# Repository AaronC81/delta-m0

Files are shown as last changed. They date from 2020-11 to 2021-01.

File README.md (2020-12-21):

# Delta M0

## What is this?

Delta M0 is a **basic, compact scientific calculator** based on an STM32F0
microcontroller.

In use | Front | Back
:-:|:-:|:-:
My hand holding the Delta M0, showing the result of 2 plus 2. | The front of the Delta M0. It has a matrix of 4 columns and 5 rows of buttons, a small OLED display, a power switch on the side, and a 6-pin serial programming header on the top. | The back of the Delta M0. It has a JST battery connector on the top, a battery controller IC, an STM32 microcontroller, and some supporting passive components.

## How well does it work?

It does _work_, but you probably don't want to use it as an actual calculator
yet. The software is really lacking.

## Project structure

This is based off the
[libopencm3 template](https://github.com/libopencm3/libopencm3-template).

  - `my-project` contains the C code for the firmware.
  - `test` is a small set of unit tests which you can run with `./test/run`.
  - `hardware` contains the KiCad files for the PCB. 

# Building

Make sure you clone with `--recurse-submodules`!

Then:

```
make -C libopencm3
make -C my-project
```

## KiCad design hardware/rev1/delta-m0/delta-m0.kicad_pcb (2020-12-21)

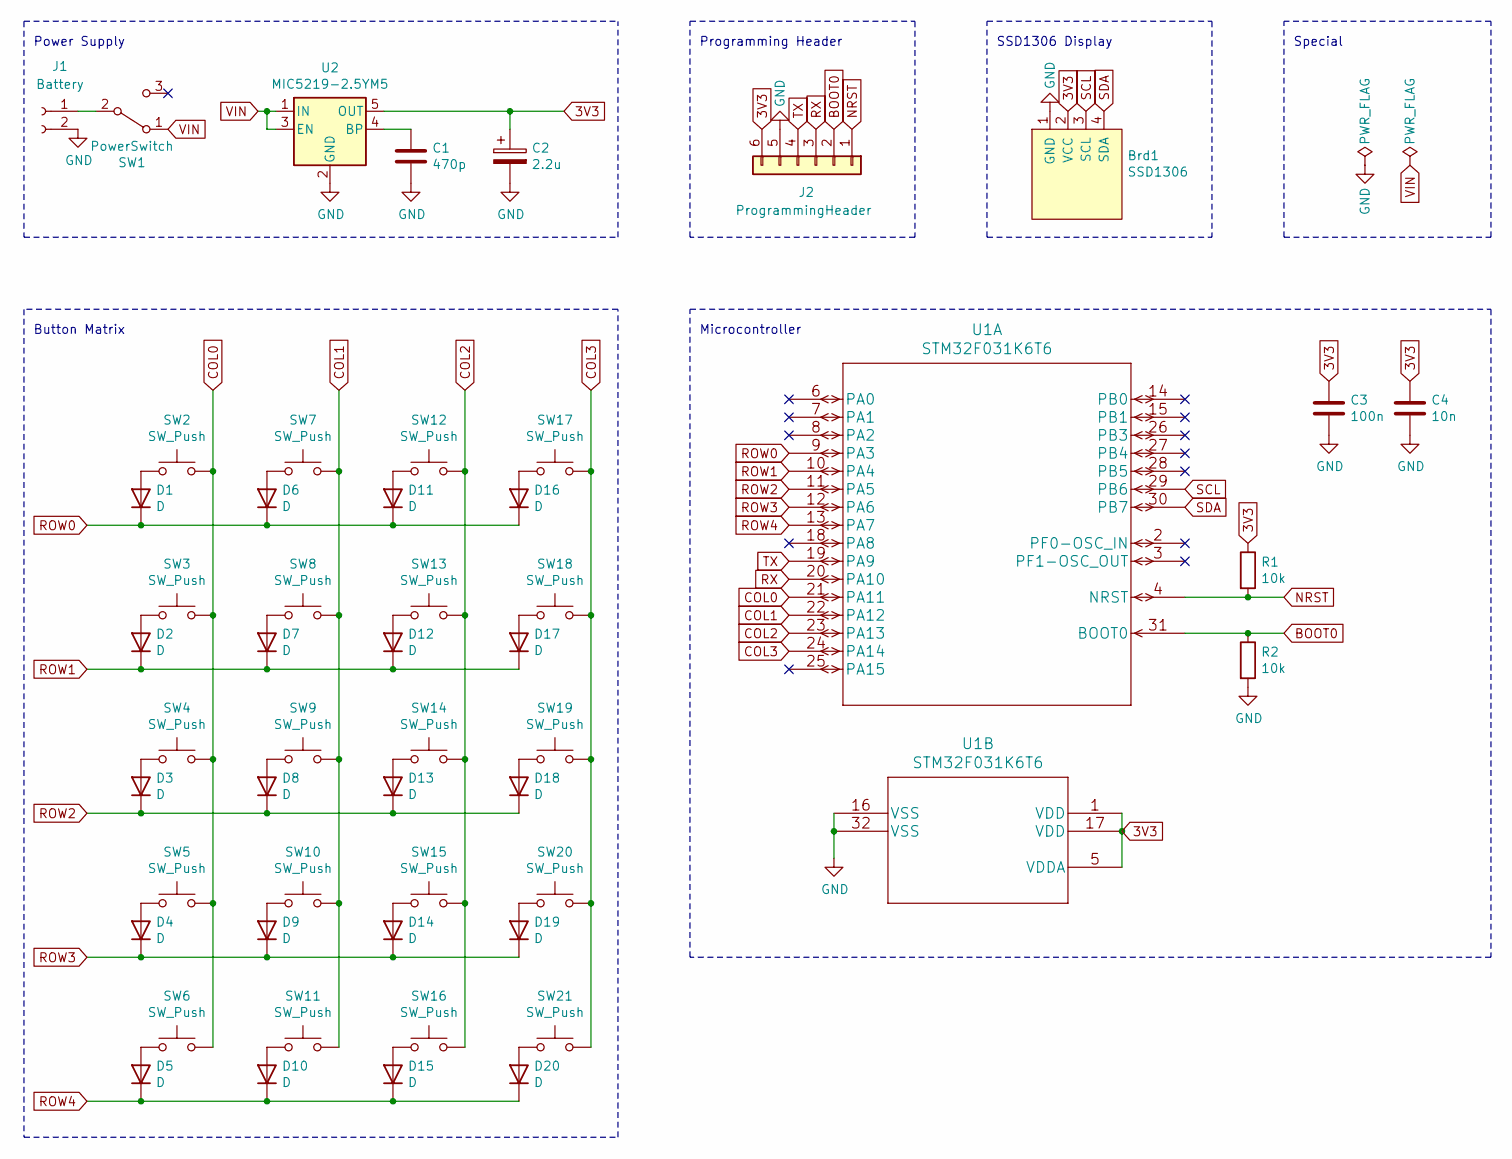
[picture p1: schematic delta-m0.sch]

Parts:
Brd1: SSD1306; 128x64OLED
C1: 470p; C_0805_2012Metric_Pad1.18x1.45mm_HandSolder
C2: 2.2u; C_0805_2012Metric_Pad1.18x1.45mm_HandSolder
C3: 100n; C_0805_2012Metric_Pad1.18x1.45mm_HandSolder
C4: 10n; C_0805_2012Metric_Pad1.18x1.45mm_HandSolder
D1, D2, D3, D4, D5, D6, D7, D8, D9, D10, D11, D12, D13, D14, D15, D16, D17, D18, D19, D20: D; D_SOD-123
J1: Battery; JST_PH_S2B-PH-K_1x02_P2.00mm_Horizontal
J2: ProgrammingHeader; PinSocket_1x06_P2.54mm_Vertical
R1, R2: 10k; R_0603_1608Metric_Pad0.98x0.95mm_HandSolder
SW1: PowerSwitch; SW_SPDT_CK-JS102011SAQN
SW2, SW3, SW4, SW5, SW6, SW7, SW8, SW9, SW10, SW11, SW12, SW13, SW14, SW15, SW16, SW17, SW18, SW19, SW20, SW21: SW_Push; PTS636
U1: STM32F031K6T6; TQFP-32_7x7mm_P0.8mm
U2: MIC5219-2.5YM5; SOT-23-5

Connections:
3V3: Brd1.2 (VCC), C2.1, C3.1, C4.1, J2.6, R1.1, U1.1 (VDD), U1.5 (VDDA), U1.17 (VDD), U2.5 (OUT)
BOOT0: J2.2, R2.1, U1.31 (BOOT0)
COL0: SW2.2, SW3.2, SW4.2, SW5.2, SW6.2, U1.21 (PA11)
COL1: SW7.2, SW8.2, SW9.2, SW10.2, SW11.2, U1.22 (PA12)
COL2: SW12.2, SW13.2, SW14.2, SW15.2, SW16.2, U1.23 (PA13)
COL3: SW17.2, SW18.2, SW19.2, SW20.2, SW21.2, U1.24 (PA14)
GND: Brd1.1 (GND), C1.2, C2.2, C3.2, C4.2, J1.2, J2.5, R2.2, U1.16 (VSS), U1.32 (VSS), U2.2 (GND)
NRST: J2.1, R1.2, U1.4 (NRST)
unnamed: C1.1, U2.4 (BP)
unnamed: D1.2 (A), SW2.1
unnamed: D2.2 (A), SW3.1
unnamed: D3.2 (A), SW4.1
unnamed: D4.2 (A), SW5.1
unnamed: D5.2 (A), SW6.1
unnamed: D6.2 (A), SW7.1
unnamed: D7.2 (A), SW8.1
unnamed: D8.2 (A), SW9.1
unnamed: D9.2 (A), SW10.1
unnamed: D10.2 (A), SW11.1
unnamed: D11.2 (A), SW12.1
unnamed: D12.2 (A), SW13.1
unnamed: D13.2 (A), SW14.1
unnamed: D14.2 (A), SW15.1
unnamed: D15.2 (A), SW16.1
unnamed: D16.2 (A), SW17.1
unnamed: D17.2 (A), SW18.1
unnamed: D18.2 (A), SW19.1
unnamed: D19.2 (A), SW20.1
unnamed: D20.2 (A), SW21.1
unnamed: J1.1, SW1.2 (B)
ROW0: D1.1 (K), D6.1 (K), D11.1 (K), D16.1 (K), U1.9 (PA3)
ROW1: D2.1 (K), D7.1 (K), D12.1 (K), D17.1 (K), U1.10 (PA4)
ROW2: D3.1 (K), D8.1 (K), D13.1 (K), D18.1 (K), U1.11 (PA5)
ROW3: D4.1 (K), D9.1 (K), D14.1 (K), D19.1 (K), U1.12 (PA6)
ROW4: D5.1 (K), D10.1 (K), D15.1 (K), D20.1 (K), U1.13 (PA7)
RX: J2.3, U1.20 (PA10)
SCL: Brd1.3 (SCL), U1.29 (PB6)
SDA: Brd1.4 (SDA), U1.30 (PB7)
TX: J2.4, U1.19 (PA9)
VIN: SW1.1 (A), U2.1 (IN), U2.3 (EN)

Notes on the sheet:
Power Supply
Programming Header
SSD1306 Display
Microcontroller
Button Matrix
Special

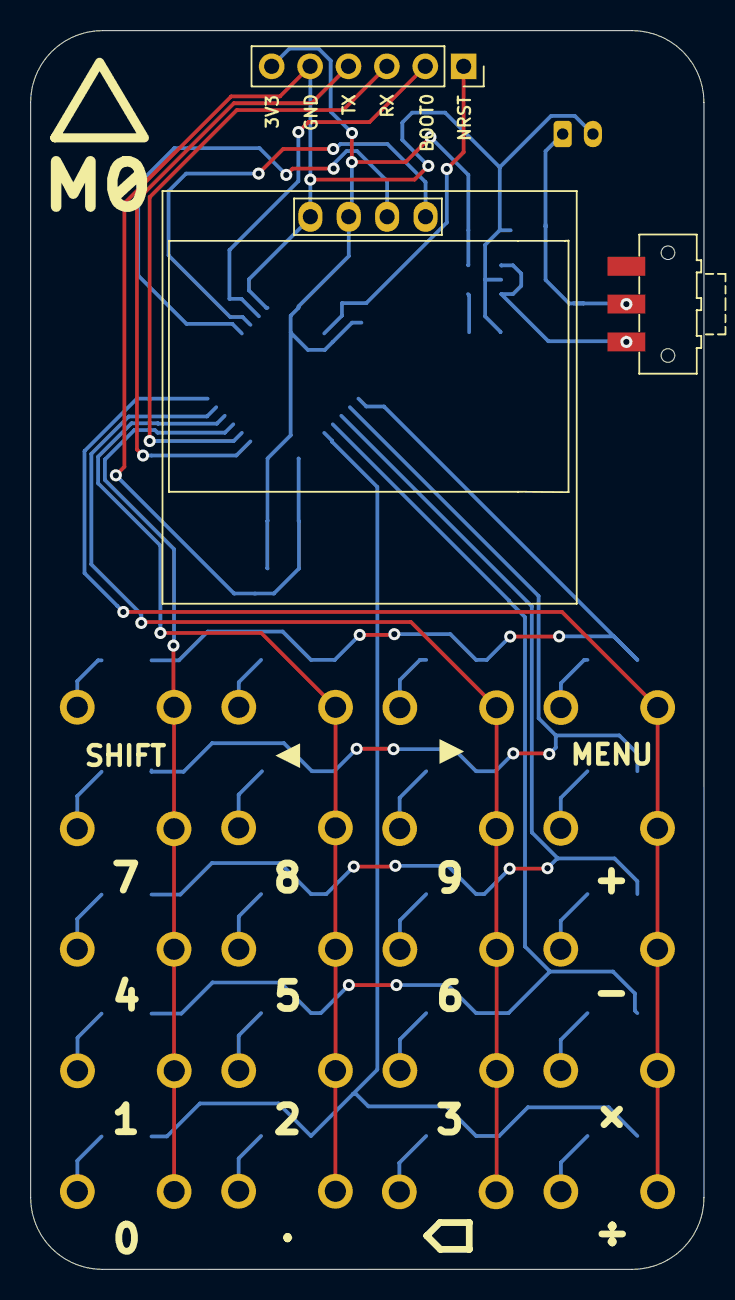
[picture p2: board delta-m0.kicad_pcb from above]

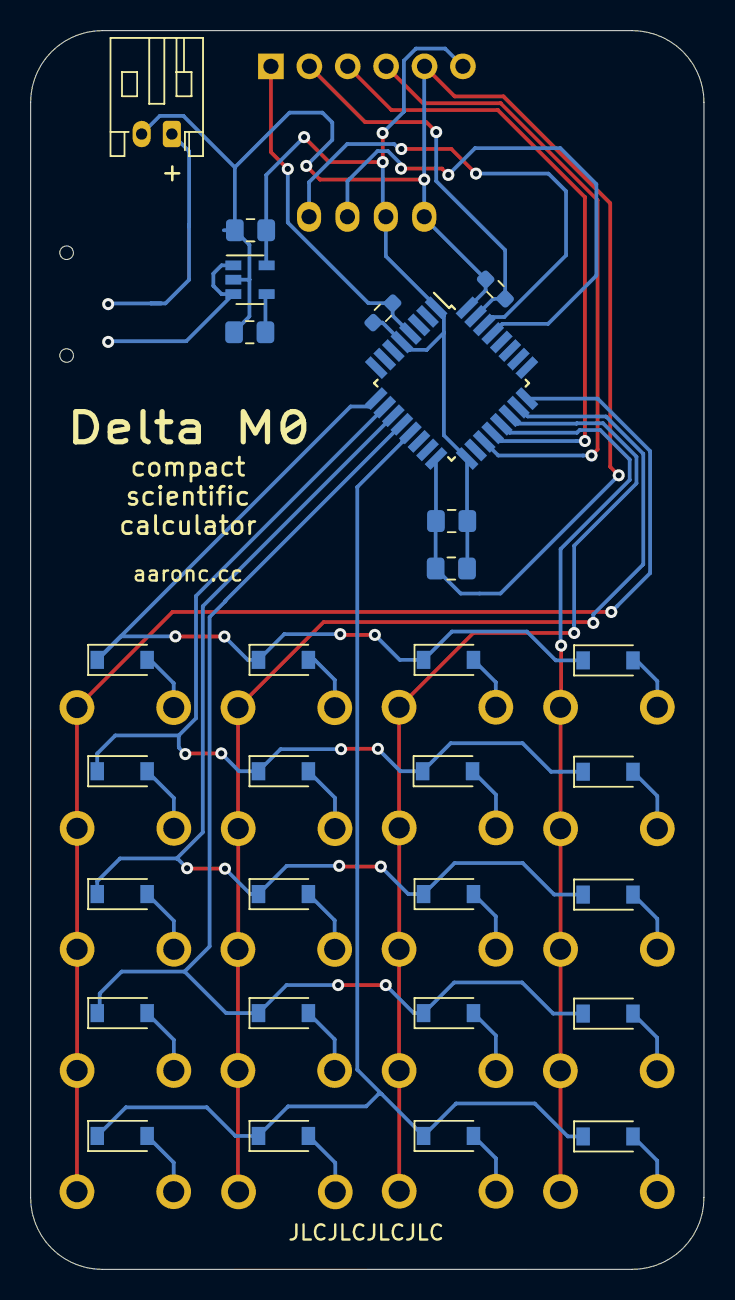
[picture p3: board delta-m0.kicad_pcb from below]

Board: 2 copper layers, 44.5 x 82.0 mm, 52 parts (29 on the bottom side), 40 nets.

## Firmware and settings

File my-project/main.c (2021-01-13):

#include <libopencm3/stm32/i2c.h>
#include <libopencm3/stm32/rcc.h>
#include <libopencm3/stm32/gpio.h>
#include <libopencm3/stm32/usart.h>
#include "ssd1306.h"
#include "keypad.h"
#include "tokens.h"
#include "input.h"
#include "key_mapping.h"
#include "assets/graphics.h"

uint8_t x;

int main(void) {
	// Hang on for a little bit after starting up, or the display is unhappy
	// (This is about 0.2 seconds)
	for (volatile uint32_t i = 0; i < 100000; i++);

	init();
	ssd1306_fill(0); // Blank

	while (1) {
		uint8_t row, col;
		if (keypad_get_pressed(&row, &col)) {
			key_mapping_action(row, col);

			// Shift indicator
			ssd1306_set_position(0, 0);
			ssd1306_data_start(1);
			ssd1306_data(key_shift ? 0xFF : 0x00);

			input_redraw_tokens(2, INPUT_ENTRY_PAGE);
			input_evaluate();

			for (volatile int i = 0; i < 200000; i++);
		}
	}
}

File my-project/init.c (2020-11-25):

#include "init.h"

#include <libopencm3/stm32/i2c.h>
#include <libopencm3/stm32/rcc.h>
#include <libopencm3/stm32/gpio.h>
#include <libopencm3/stm32/usart.h>
#include "ssd1306.h"
#include "keypad.h"

// PB6: SCL
// PB7: SDA

// PA9/PA10: USART

void init(void) {
    // Set up GPIO
	rcc_periph_clock_enable(RCC_GPIOA);
	rcc_periph_clock_enable(RCC_GPIOB);

	// Set up GPIO for USART1
	gpio_mode_setup(GPIOA, GPIO_MODE_AF, GPIO_PUPD_NONE, GPIO9 | GPIO10);
	gpio_set_af(GPIOA, GPIO_AF1, GPIO9 | GPIO10);

	// Set up USART1
	rcc_periph_clock_enable(RCC_USART1);
	usart_disable(USART1);
	usart_set_databits(USART1, 8);
	usart_set_baudrate(USART1, 9600);
	usart_set_mode(USART1, USART_MODE_TX);
	usart_enable(USART1);
	
	// Set up I2C1
	rcc_periph_clock_enable(RCC_I2C1);
	i2c_enable_autoend(I2C1);
	I2C_TIMINGR(I2C1) = 0x00100306 | (I2C_TIMINGR(I2C1) & 0x0F000000);
	i2c_peripheral_enable(I2C1);

	// Set up GPIO for I2C1
	gpio_mode_setup(GPIOB, GPIO_MODE_AF, GPIO_PUPD_NONE, GPIO6 | GPIO7);
	gpio_set_output_options(GPIOB, GPIO_OTYPE_OD, GPIO_OSPEED_LOW, GPIO6 | GPIO7);
	gpio_set_af(GPIOB, GPIO_AF1, GPIO6 | GPIO7);
    
    // Init display
    ssd1306_init();

    // Init keypad
    keypad_init();
}

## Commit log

2020-11-25 Fix insertion trashing everything afterwards
2020-11-25 Fix insertion... again
2020-11-30 Draw calculation results, fix display not working on power-on
    [main.c]
2020-12-02 Added hardware
    [delta-m0.kicad_pcb, delta-m0.sch]
2020-12-21 Update Kicad PCB
    [delta-m0.kicad_pcb]
2020-12-21 Update .gitignore for gerbers
2021-01-12 Add shift+del=clear, fix delete, fix insert at idx 0
2021-01-14 Print 0 if the answer is 0, rather than nothing
